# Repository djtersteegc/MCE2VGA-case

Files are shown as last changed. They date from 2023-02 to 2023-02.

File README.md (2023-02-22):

Yet another case design for the MCE2VGA version 2.0 PCB available from https://sites.google.com/site/tandycocoloco/mda-cga-ega-to-vga.  Wanted something with a more enclosed case than the current designs out there.  All required switchs, buttons, and LED's are brought to the top of case with extenders and light pipes. Only the DIP switch requires a small tool like a mini screwdriver to adjust settings.

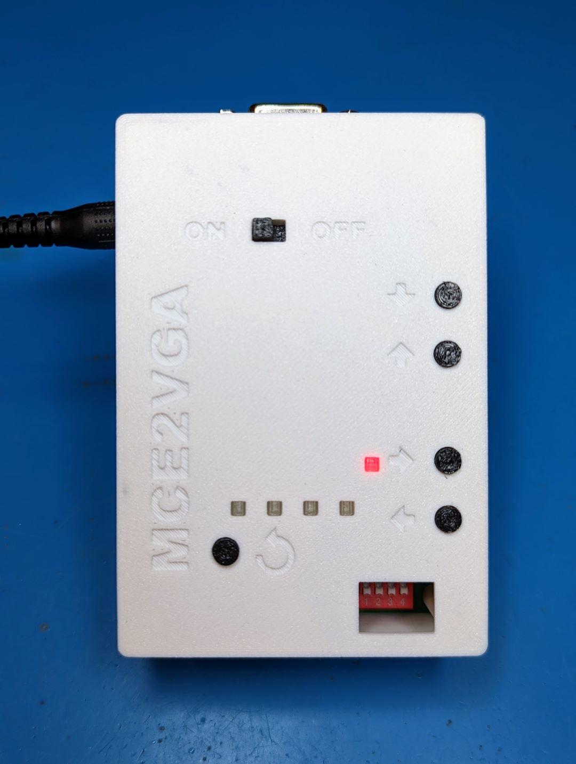
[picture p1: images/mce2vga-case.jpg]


# Printing and Assembly

Optimized to print at 0.2mm layer heights with no supports needed.  Print four of the **mce2vga-button-adjust** buttons, and five of the light pipes in a clear filament like nartural PLA, and one of everything else.  The light pipes are press fit with a small lip on the top so make sure to align them correctly in the holes. Assemble with four M3x8mm (or longer) taper head screws. Clearances are tight, so you may have to drill out the button holes with a 5mm bit to get a perfect hole.

# Design Files

STEP models of the MCE2VGA and CoreEP4CE6 boards are in the **KiCad** directory.  Design was done in [DesignSpark Mechanical 6.0](https://www.rs-online.com/designspark/mechanical-software) if you want modify it further.

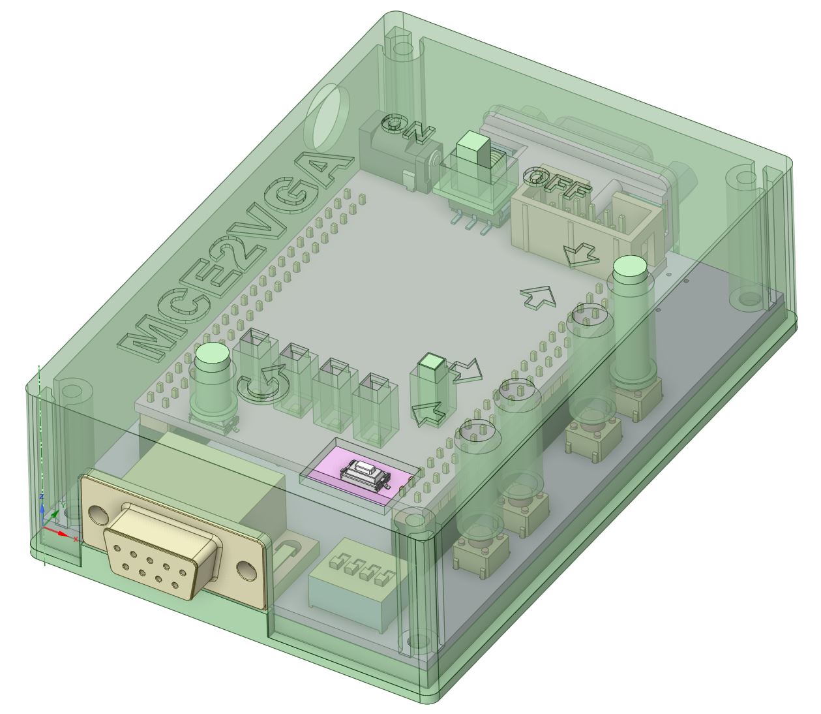
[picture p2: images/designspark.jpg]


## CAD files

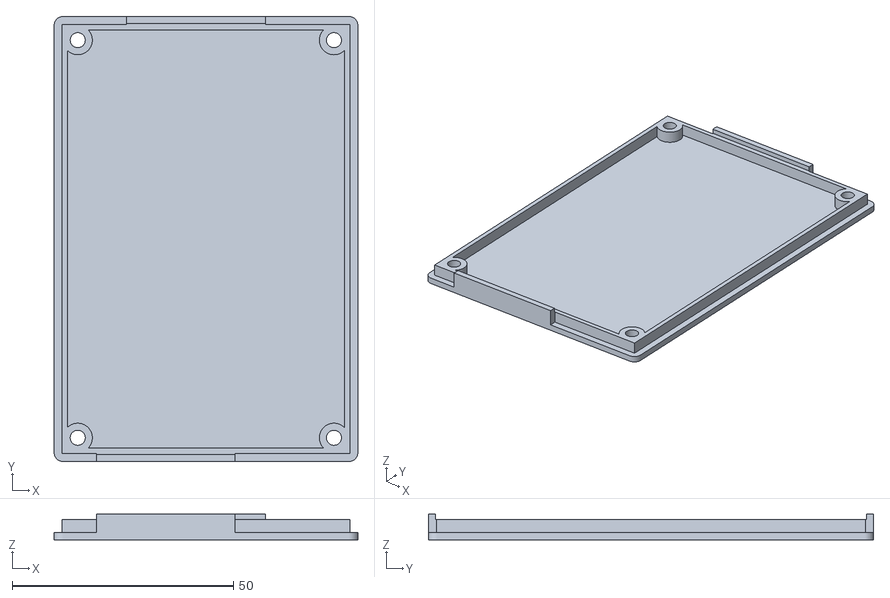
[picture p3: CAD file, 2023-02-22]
STL/mce2vga-lid.stl
68.7 x 100.6 x 5.80

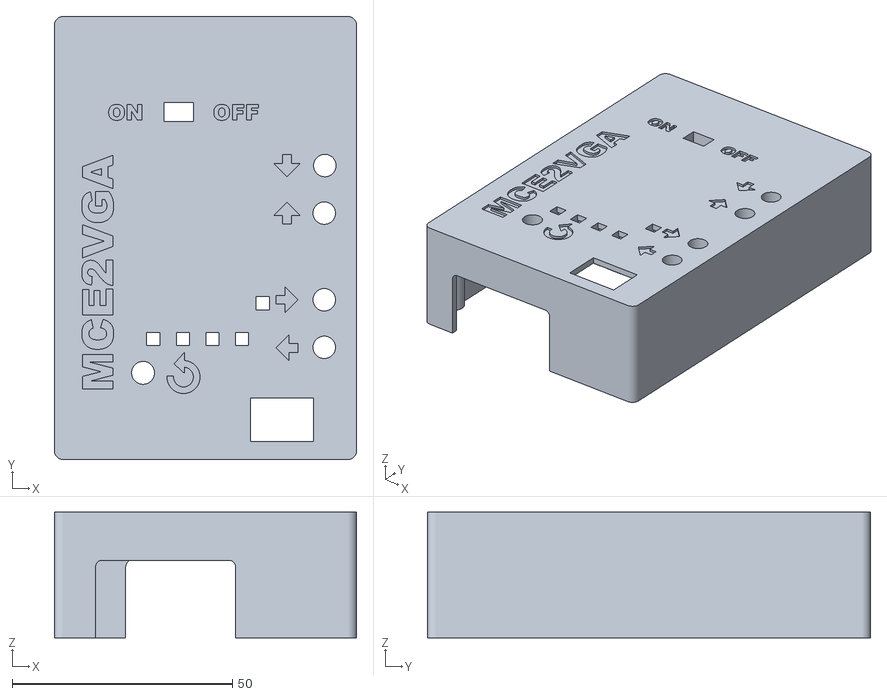
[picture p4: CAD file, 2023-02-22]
STL/mce2vga-body.stl
68.7 x 100.6 x 28.6

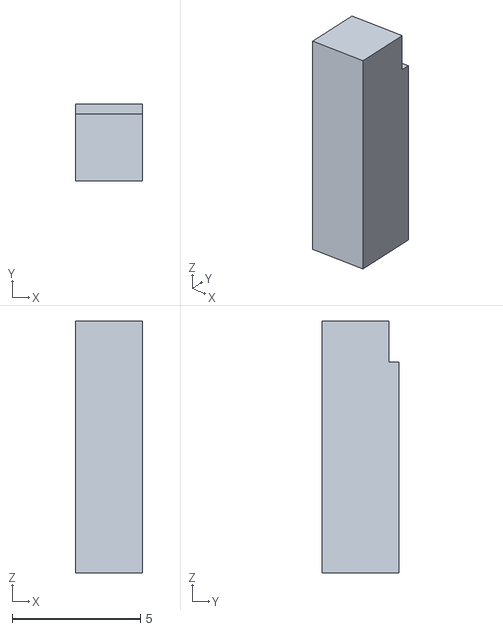
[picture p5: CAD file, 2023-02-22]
STL/mce2vga-light-pipe.stl
2.60 x 3.00 x 9.81

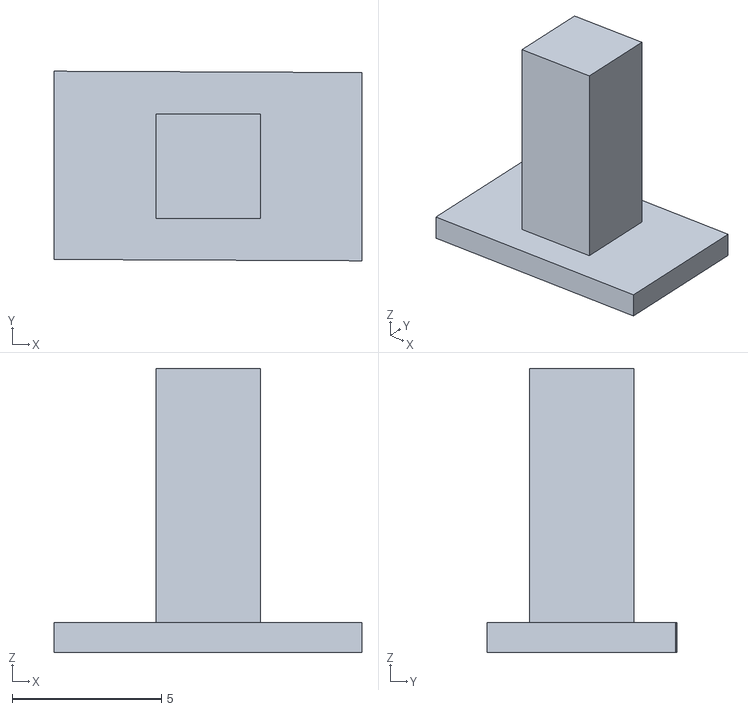
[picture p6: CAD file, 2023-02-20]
STL/mce2vga-switch.stl
10.3 x 6.34 x 9.50

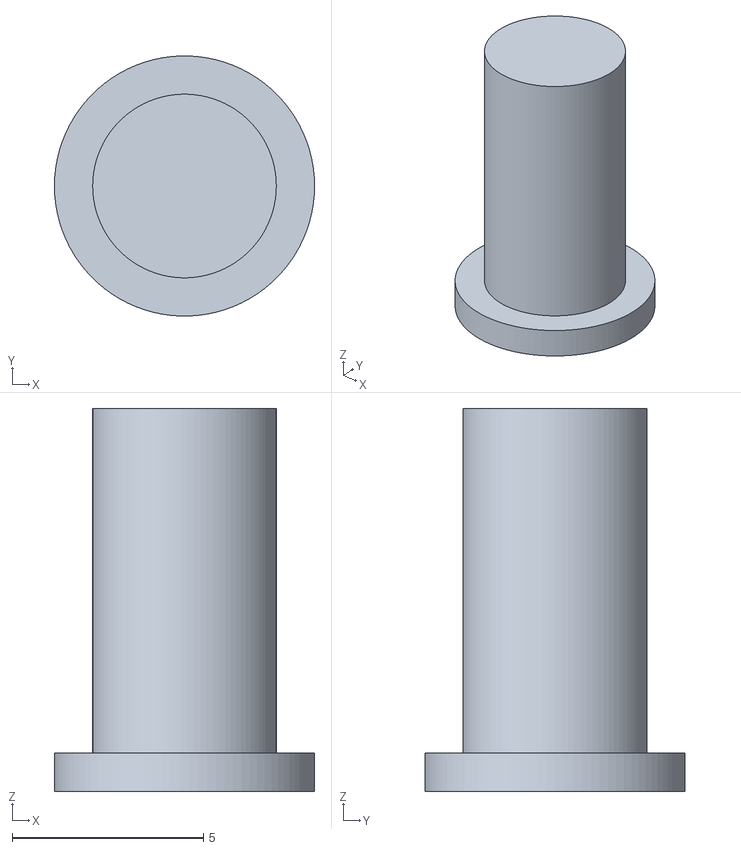
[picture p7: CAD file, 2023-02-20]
STL/mce2vga-button-reset.stl
6.80 x 6.80 x 10.0

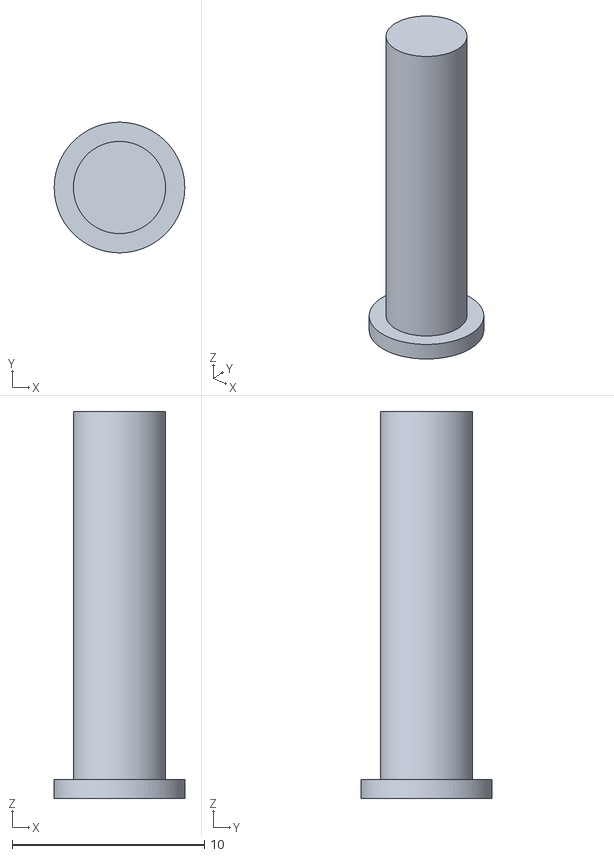
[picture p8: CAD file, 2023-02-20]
STL/mce2vga-button-adjust.stl
6.80 x 6.80 x 20.2

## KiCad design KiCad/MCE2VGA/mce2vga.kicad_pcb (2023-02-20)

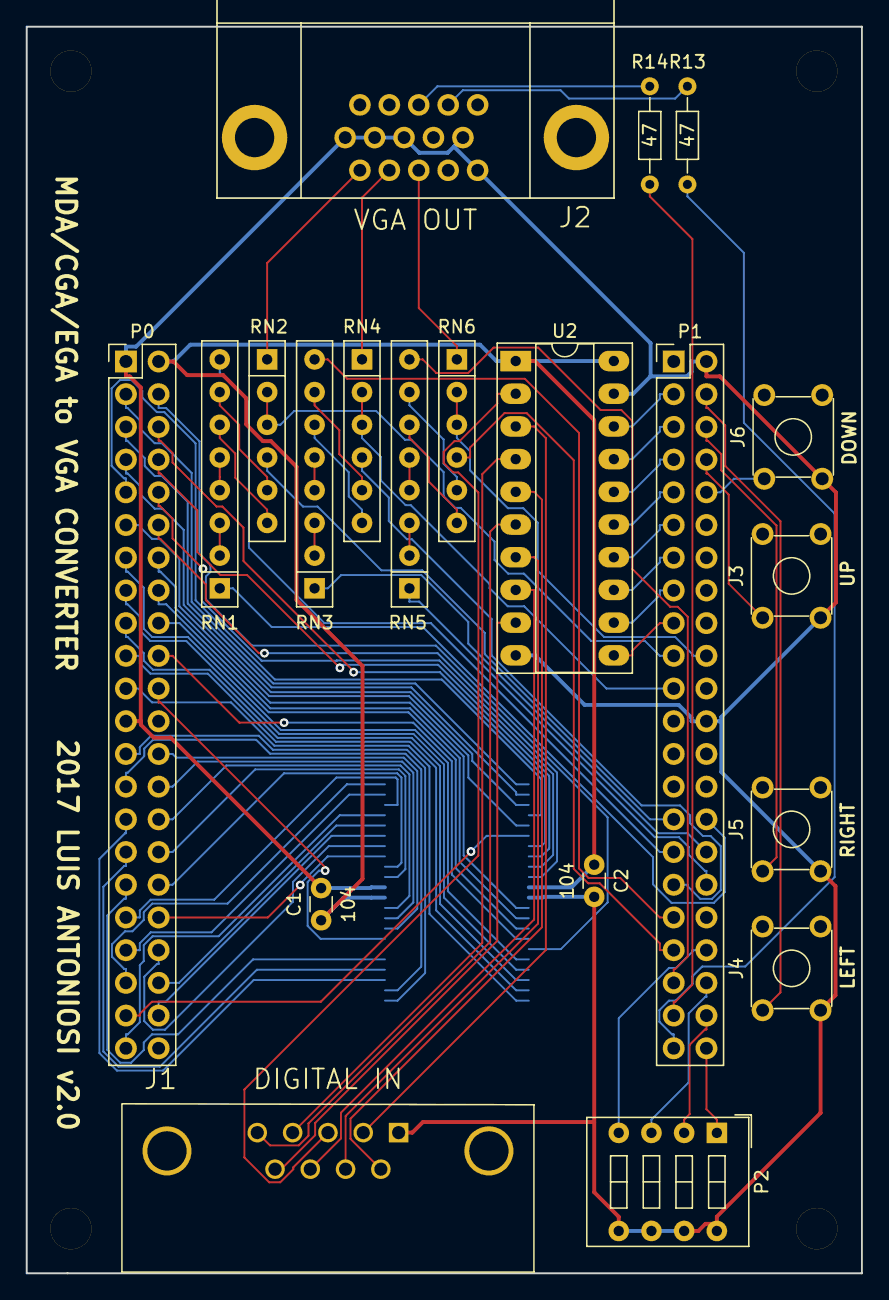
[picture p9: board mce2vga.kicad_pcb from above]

Board: 2 copper layers, 64.9 x 96.8 mm, 25 parts (1 on the bottom side), 96 nets.

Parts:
C1, C2: 104; C_Disc_D3.0mm_W1.6mm_P2.50mm
J1: DIGITAL IN; DB9F
J2: VGA OUT; HD15_B-HD15F
J3, J4, J5, J6: Conn_02x02_Counter_Clockwise; SW_TH_Tactile_Omron_B3F-10xx
P0, P1: CONN_02X22; Pin_Header_Straight_2x22_Pitch2.54mm
P2: SW1; SW_DIP_x4_W7.62mm_Slide
P3, P4, P5, P6: MOUNT_HOLE; MountingHole_3.2mm_M3
R13, R14: 47; R_Axial_DIN0204_L3.6mm_D1.6mm_P7.62mm_Horizontal
RN1, RN3, RN5: R_Pack04_SIP; R_Array_SIP8
RN2, RN4, RN6: R_Network05; R_Array_SIP6
U1: AS7C34098A; SOP80P1176X120-44N
U2: 74LVC245; DIP-20_W7.62mm_Socket_LongPads

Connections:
B0: P1.34, RN5.1
B1: P1.39, RN5.8
B2: P1.37, RN6.4
B3: P1.20, RN6.2, RN6.3
BLUE: J2.3, RN6.1
DOWN: J6.1, P1.10
G0: P1.32, RN3.1
G1: P1.35, RN3.8
G2: P1.33, RN4.4
G3: P1.21, RN4.2, RN4.3
GND: C1.2, C2.2, J1.1, J2.5, J2.6, J2.7, J2.8, J2.10, J3.3, J4.3, J5.3, J6.3, P0.1, P0.23, P1.2, P1.24, P2.5, P2.6, P2.7, P2.8, U1.12, U1.34, U2.10, U2.19
GREEN: J2.2, RN4.1
H: J1.8, U2.8
HS: J2.13, R14.1
HSYNC: P1.41, R14.2
H_25: P1.15, U2.12
LEFT: J4.1, P1.4
unnamed: RN1.2, RN1.3
unnamed: RN1.4, RN1.5
unnamed: RN1.6, RN2.6
unnamed: RN1.7, RN2.5
unnamed: RN3.2, RN3.3
unnamed: RN3.4, RN3.5
unnamed: RN3.6, RN4.6
unnamed: RN3.7, RN4.5
unnamed: RN5.2, RN5.3
unnamed: RN5.4, RN5.5
unnamed: RN5.6, RN6.6
unnamed: RN5.7, RN6.5
PB: J1.5, U2.6
PB_25: P1.11, U2.14
PG: J1.4, U2.4
PG_25: P1.7, U2.16
PR: J1.3, U2.2
PR_25: P1.3, U2.18
R0: P1.30, RN1.1
R1: P1.31, RN1.8
R2: P1.29, RN2.4
R3: P1.19, RN2.2, RN2.3
RED: J2.1, RN2.1
RIGHT: J5.1, P1.6
SB: J1.7, U2.7
SB_25: P1.13, U2.13
SG: J1.6, U2.5
SG_25: P1.9, U2.15
SR: J1.2, U2.3
SRAM_ADDR0: P0.3, U1.1
SRAM_ADDR1: P0.5, U1.2
SRAM_ADDR2: P0.7, U1.3
SRAM_ADDR3: P0.9, U1.4
SRAM_ADDR4: P0.11, U1.5
SRAM_ADDR5: P0.13, U1.18
SRAM_ADDR6: P0.15, U1.19
SRAM_ADDR7: P0.17, U1.20
SRAM_ADDR8: P0.19, U1.21
SRAM_ADDR9: P0.21, U1.22
SRAM_ADDR10: P0.25, U1.23
SRAM_ADDR11: P0.27, U1.24
SRAM_ADDR12: P0.29, U1.25
SRAM_ADDR13: P0.31, U1.26
SRAM_ADDR14: P0.33, U1.27
SRAM_ADDR15: P0.35, U1.42
SRAM_ADDR16: P0.37, U1.43
SRAM_ADDR17: P0.39, U1.44
SRAM_DQ0: P0.6, U1.7
SRAM_DQ1: P0.8, U1.8
SRAM_DQ2: P0.10, U1.9
SRAM_DQ3: P0.12, U1.10
SRAM_DQ4: P0.14, U1.13
SRAM_DQ5: P0.16, U1.14
SRAM_DQ6: P0.18, U1.15
SRAM_DQ7: P0.20, U1.16
SRAM_DQ8: P0.22, U1.29
SRAM_DQ9: P0.26, U1.30
SRAM_DQ10: P0.28, U1.31
SRAM_DQ11: P0.30, U1.32
SRAM_DQ12: P0.32, U1.35
SRAM_DQ13: P0.34, U1.36
SRAM_DQ14: P0.36, U1.37
SRAM_DQ15: P0.38, U1.38
SR_25: P1.5, U2.17
SW0: P1.44, P2.1
SW1: P1.42, P2.2
SW2: P1.40, P2.3
SW3: P1.38, P2.4
UP: J3.1, P1.8
V: J1.9, U2.9
VCC33V: C1.1, C2.1, P0.2, U1.11, U1.33, U2.1, U2.20
VS: J2.14, R13.1
VSYNC: P1.43, R13.2
V_25: P1.17, U2.11
~SRAM_CE: P0.41, U1.6
~SRAM_LB: P0.42, U1.39
~SRAM_OE: P0.43, U1.41
~SRAM_UB: P0.40, U1.40
~SRAM_WE: P0.4, U1.17
